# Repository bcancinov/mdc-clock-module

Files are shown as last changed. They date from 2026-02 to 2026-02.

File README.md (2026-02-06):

# mdc-clock-module
Modular Detector Controller Clock Module

## Overview
Clock generator module with jitter cleaning. Takes a 10 MHz input and generates an ultra low jitter 100 MHz output with zero delay for the detector sequencer.
Provides up to three low-jitter synchronized clock outputs.

## Key ICs
- Jitter attenuator / clock multiplier: `SI5394J-A-GM`
  - DSPLL + MultiSynth architecture for ultra-low jitter clock generation.
  - Supports free-run, synchronous, and holdover modes with hitless switching between inputs.
  - Programmable via serial interface with on-chip NVM for power-up configuration.
  - A-grade devices use an external XTAL or XO reference.
- LDO: `TPS7A20`
  - Low-noise, high-PSRR LDO for clean supply rails to the timing IC.
  - Low IQ with good load/line transient performance for sensitive analog circuits.

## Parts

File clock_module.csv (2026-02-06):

Reference | Qty | M | MPN | Description
C1,C2,C3,C4,C5,C6,C7,C8,C9,C10,C11,C20,C21 | 13 | VENKEL | C0402X7R100-105KNP-CT | 1 µF ±10% 10V Ceramic Capacitor X7R 0402 (1005 Metric)
C12,C13,C14,C15,C16,C17,C18,C19 | 8 | MURATA | GCM155R71C104KA55J | 0.1 µF ±10% 16V Ceramic Capacitor X7R 0402 (1005 Metric)
H1,H2 | 2 |  |  | Mounting Hole with connection
J1 | 1 | Samtec | LSHM-130-04.0-L-DV-A-N-K-TR | Generic connector, double row, 02x30, odd/even pin numbering scheme (row 1 odd numbers, row 2 even numbers), script generated (kicad-library-utils/schlib/autogen/connector/)
R1,R2 | 2 | VISHAY | CRCW0402100RFKEDHP | 100 Ohms ±1% 0.2W, 1/5W Chip Resistor 0402 (1005 Metric) Automotive AEC-Q200, Pulse Withstanding Thick Film
U1 | 1 | Skyworks | SI5394J-A-GM | Clock Synthesizer / Jitter Cleaner Single PLL jitter attenuator with ext crystal: 4-outputs up to 1028 MHz; integer+fractional
U2 | 1 | Texas Instruments | TPS7A2018PDBVR

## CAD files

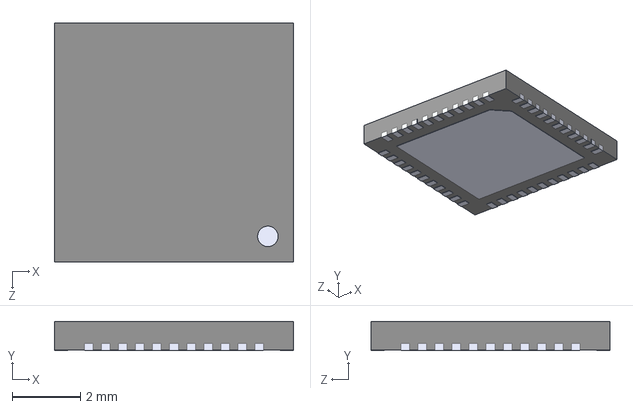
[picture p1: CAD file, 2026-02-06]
step/SI5394A-A09386-GM.stp
7.00 x 0.85 x 7.00 mm

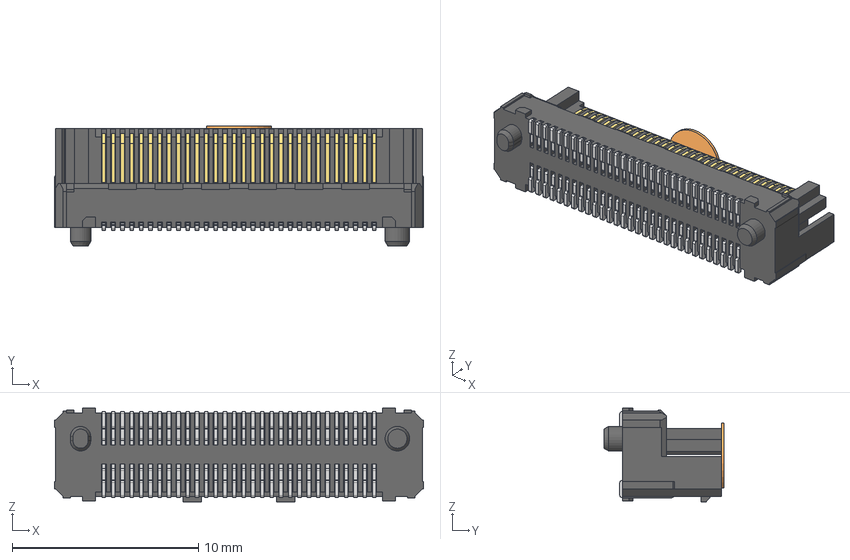
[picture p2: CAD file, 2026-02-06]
step/LSHM-130-04.0-L-DV-A-N-K-TR.step
19.8 x 6.45 x 5.03 mm
LSHM-30-04.0-DV-A-N_STRIP
C-185--30-04.0-L-DV1P
C-185--30-04.0-DV1P2 L
K-DOT-.138-.250-.005.pp

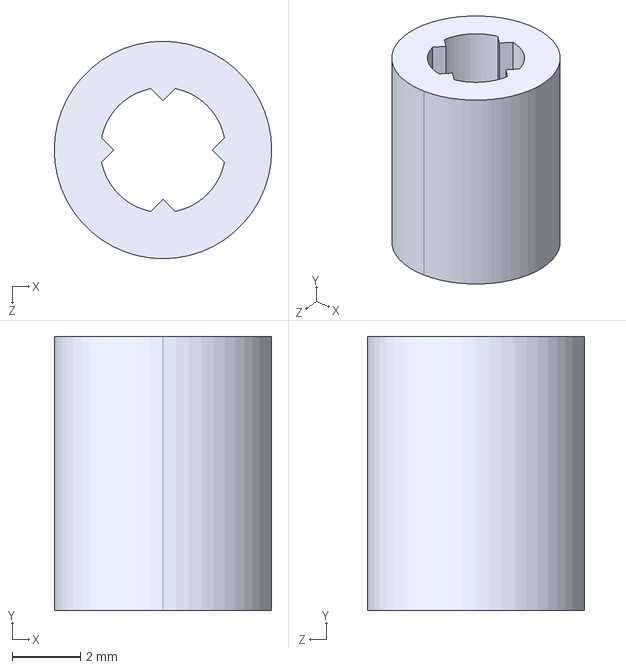
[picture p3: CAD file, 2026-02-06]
step/SRS-4-8MM.stp
6.35 x 8.00 x 6.35 mm

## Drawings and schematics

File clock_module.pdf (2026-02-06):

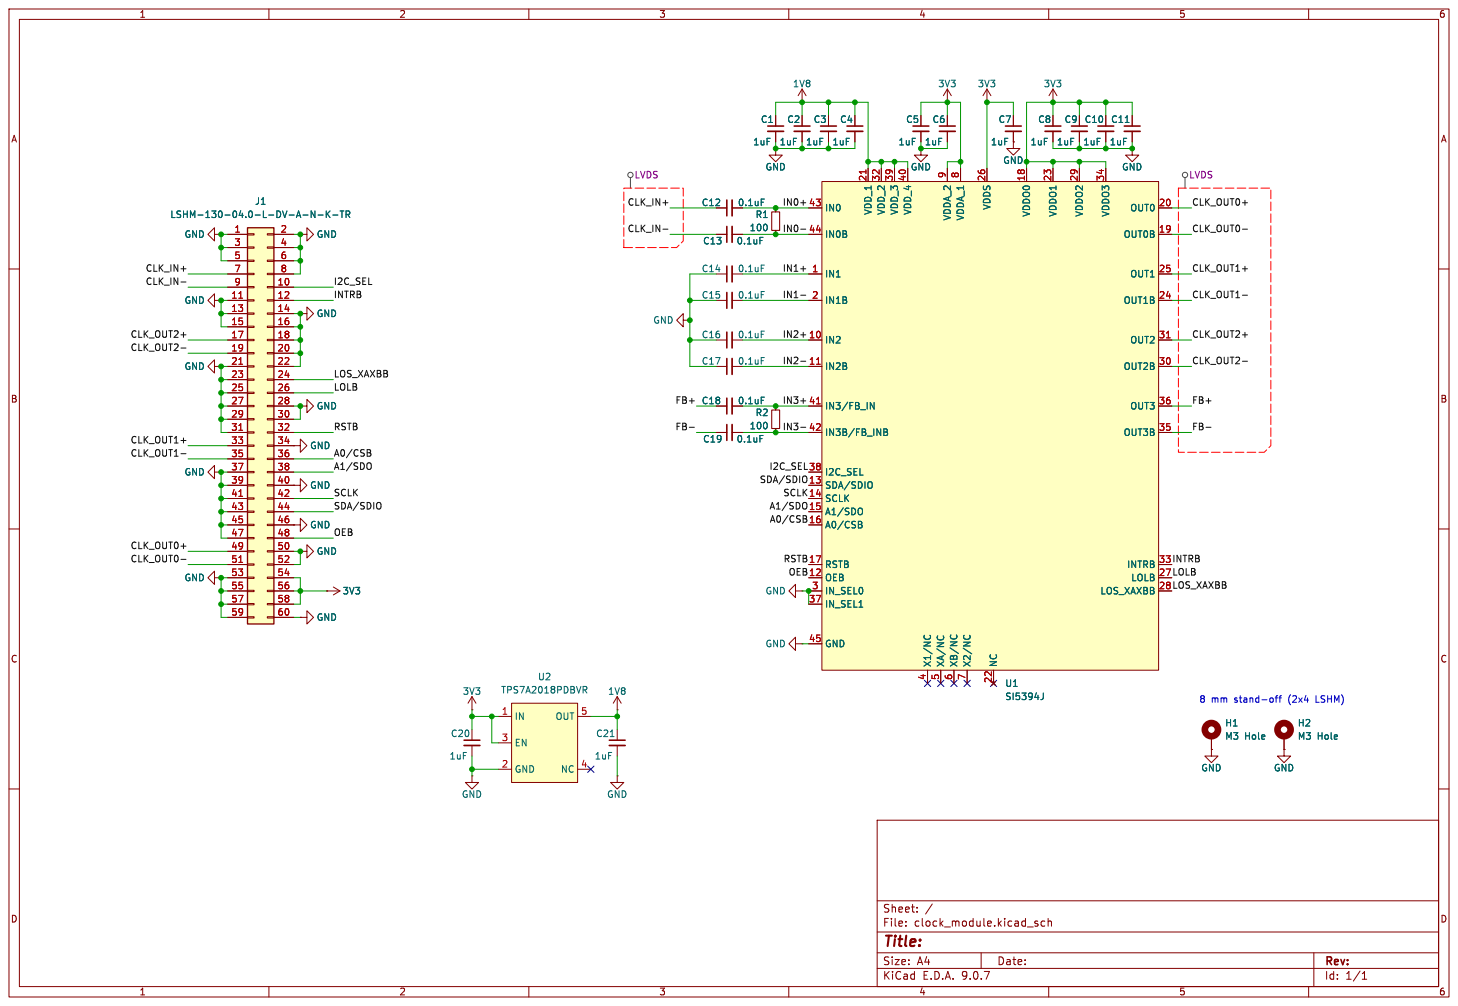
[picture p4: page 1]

Id: 1/1 Title: File: clock_module.kicad_sch Sheet: /

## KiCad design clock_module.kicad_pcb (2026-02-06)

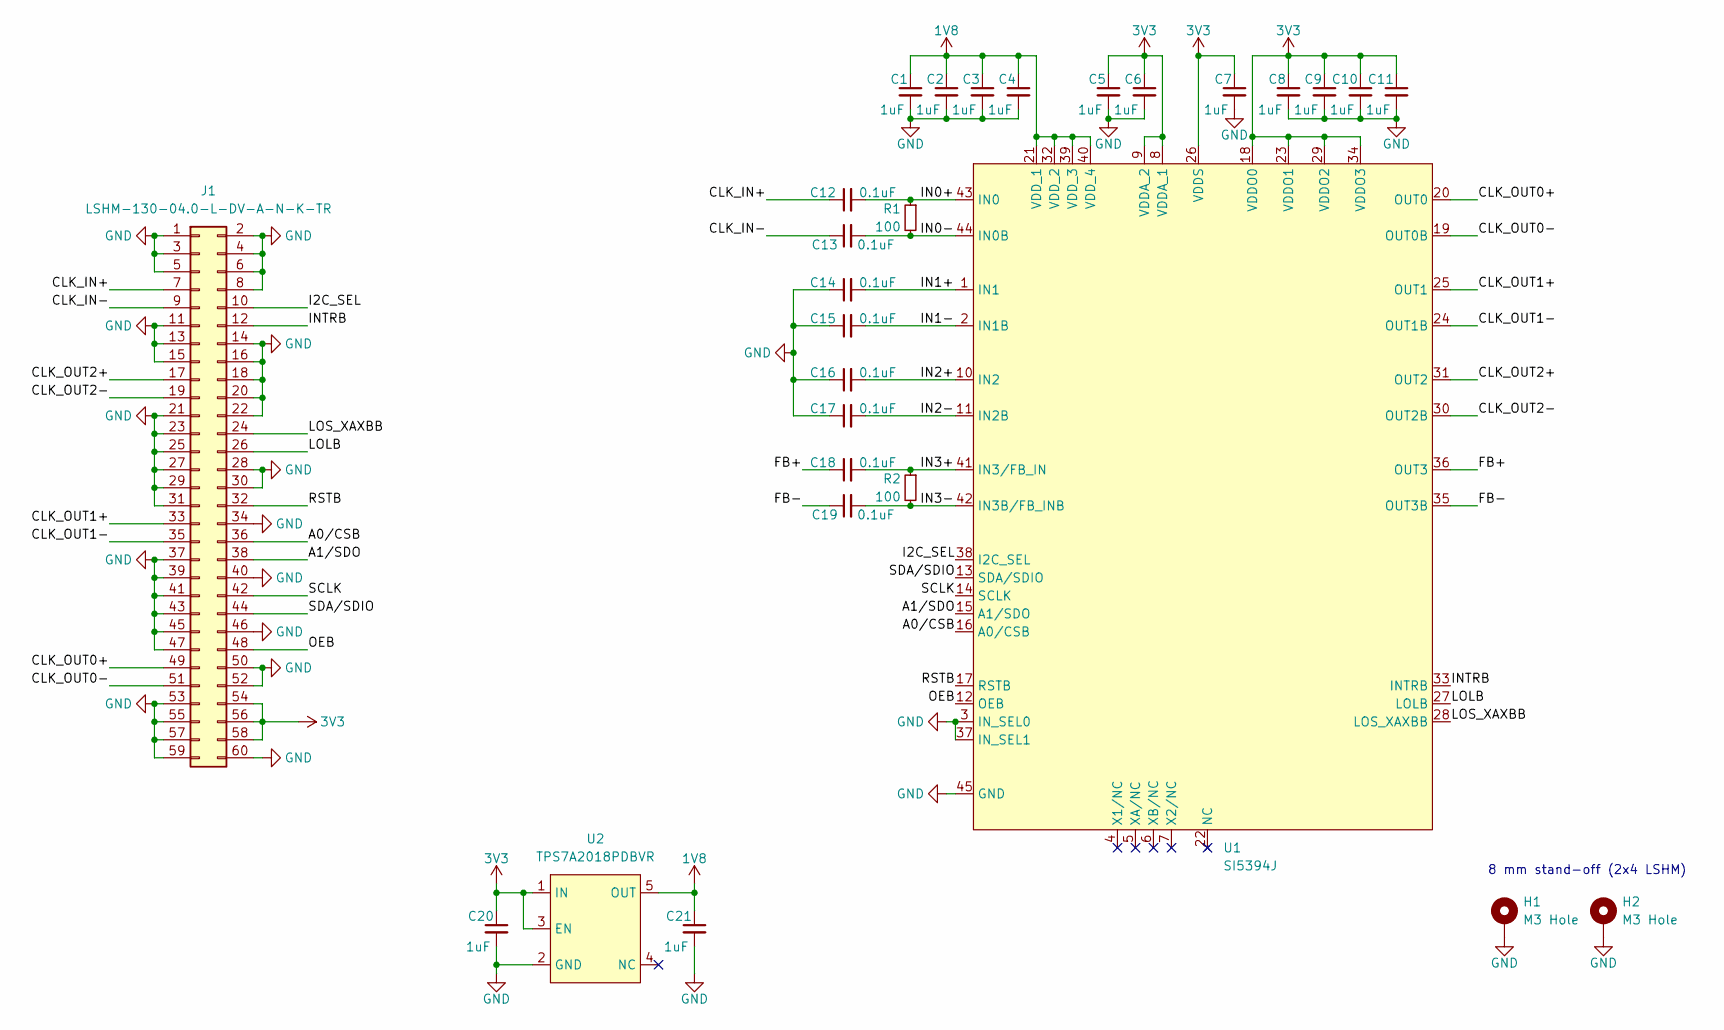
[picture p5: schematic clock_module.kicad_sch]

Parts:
C1, C2, C3, C4, C5, C6, C7, C8, C9, C10, C11, C20, C21: 1uF; C_0402_1005Metric; MPN C0402X7R100-105KNP-CT
C12, C13, C14, C15, C16, C17, C18, C19: 0.1uF; C_0402_1005Metric; MPN GCM155R71C104KA55J
H1, H2: M3 Hole; MountingHole_3.2mm_M3_Pad_Via
J1: LSHM-130-04.0-L-DV-A-N-K-TR; SAMTEC_LSHM-130-04.0-L-DV-A-N-K-TR; MPN LSHM-130-04.0-L-DV-A-N-K-TR
R1, R2: 100; R_0402_1005Metric; MPN CRCW0402100RFKEDHP
U1: SI5394J; QFN50P700X700X90-45N; MPN SI5394J-A-GM
U2: TPS7A2018PDBVR; SOT-23-5; MPN TPS7A2018PDBVR

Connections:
1V8: C1.1, C2.1, C3.1, C4.1, C21.1, U1.21 (VDD_1), U1.32 (VDD_2), U1.39 (VDD_3), U1.40 (VDD_4), U2.5 (OUT)
3V3: C5.1, C6.1, C7.1, C8.1, C9.1, C10.1, C11.1, C20.1, J1.54, J1.56, J1.58, U1.8 (VDDA_1), U1.9 (VDDA_2), U1.18 (VDDO0), U1.23 (VDDO1), U1.26 (VDDS), U1.29 (VDDO2), U1.34 (VDDO3), U2.1 (IN), U2.3 (EN)
/A0/CSB: J1.36, U1.16 (A0/CSB)
/A1/SDO: J1.38, U1.15 (A1/SDO)
/CLK_IN+: C12.1, J1.7
/CLK_IN-: C13.1, J1.9
/CLK_OUT0+: J1.49, U1.20 (OUT0)
/CLK_OUT0-: J1.51, U1.19 (OUT0B)
/CLK_OUT1+: J1.33, U1.25 (OUT1)
/CLK_OUT1-: J1.35, U1.24 (OUT1B)
/CLK_OUT2+: J1.17, U1.31 (OUT2)
/CLK_OUT2-: J1.19, U1.30 (OUT2B)
/FB+: C18.1, U1.36 (OUT3)
/FB-: C19.1, U1.35 (OUT3B)
/I2C_SEL: J1.10, U1.38 (I2C_SEL)
/IN0+: C12.2, R1.1, U1.43 (IN0)
/IN0-: C13.2, R1.2, U1.44 (IN0B)
/IN1+: C14.2, U1.1 (IN1)
/IN1-: C15.2, U1.2 (IN1B)
/IN2+: C16.2, U1.10 (IN2)
/IN2-: C17.2, U1.11 (IN2B)
/IN3+: C18.2, R2.1, U1.41 (IN3/FB_IN)
/IN3-: C19.2, R2.2, U1.42 (IN3B/FB_INB)
/INTRB: J1.12, U1.33 (INTRB)
/LOLB: J1.26, U1.27 (LOLB)
/LOS_XAXBB: J1.24, U1.28 (LOS_XAXBB)
/OEB: J1.48, U1.12 (OEB)
/RSTB: J1.32, U1.17 (RSTB)
/SCLK: J1.42, U1.14 (SCLK)
/SDA/SDIO: J1.44, U1.13 (SDA/SDIO)
GND: C1.2, C2.2, C3.2, C4.2, C5.2, C6.2, C7.2, C8.2, C9.2, C10.2, C11.2, C14.1, C15.1, C16.1, C17.1, C20.2, C21.2, H1.1, H2.1, J1.1, J1.2, J1.3, J1.4, J1.5, J1.6, J1.8, J1.11, J1.13, J1.14, J1.15, J1.16, J1.18, J1.20, J1.21, J1.22, J1.23, J1.25, J1.27, J1.28, J1.29, J1.30, J1.31, J1.34, J1.37, J1.39, J1.40, J1.41, J1.43, J1.45, J1.46, J1.47, J1.50, J1.52, J1.53, J1.55, J1.57, J1.59, J1.60, U1.3 (IN_SEL0), U1.37 (IN_SEL1), U1.45 (GND), U2.2 (GND)

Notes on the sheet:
8 mm stand-off (2x4 LSHM)

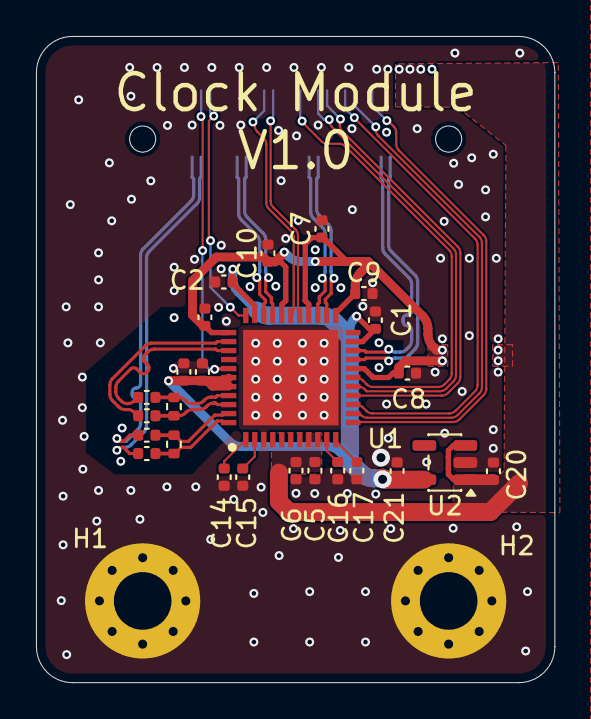
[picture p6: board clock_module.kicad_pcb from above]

Board: 4 copper layers, 28.8 x 35.9 mm, 28 parts (1 on the bottom side), 31 nets.

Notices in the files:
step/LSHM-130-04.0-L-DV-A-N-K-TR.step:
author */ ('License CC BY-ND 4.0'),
